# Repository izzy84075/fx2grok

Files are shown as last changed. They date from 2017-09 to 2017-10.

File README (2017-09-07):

-------------------------------------------------------------------------------
README
-------------------------------------------------------------------------------

The sigrok project aims at creating a portable, cross-platform,
Free/Libre/Open-Source signal analysis software suite that supports various
device types (such as logic analyzers, oscilloscopes, multimeters, and more).

The fx2grok device is intended to be the tinyiest possible Open Hardware FX2
eval board (that can be used as 8-channel logic analyzer).

Using the open-source fx2lafw firmware (and sigrok, of course) you can use
this device as 8-channel logic analyzer.

Status
------

fx2grok is currently work in progress. The PCB layout is not yet finished
and no prototypes have yet been made.

Schematics, PCB layout
----------------------

The schematics and PCB layout are available from the fx2grok git repo:

  $ git clone git://sigrok.org/fx2grok

Copyright and license
---------------------

The fx2grok schematics and layout are done from scratch in Kicad, and are
released under the CC-BY-SA 3.0 license.

They are Copyright (C) 2012-2017 Uwe Hermann <uwe@hermann-uwe.de>.

Mailing list
------------

 https://lists.sourceforge.net/lists/listinfo/sigrok-devel

IRC
---

You can find the sigrok developers in the #sigrok IRC channel on Freenode.

Website
-------

 http://sigrok.org/wiki/Fx2grok

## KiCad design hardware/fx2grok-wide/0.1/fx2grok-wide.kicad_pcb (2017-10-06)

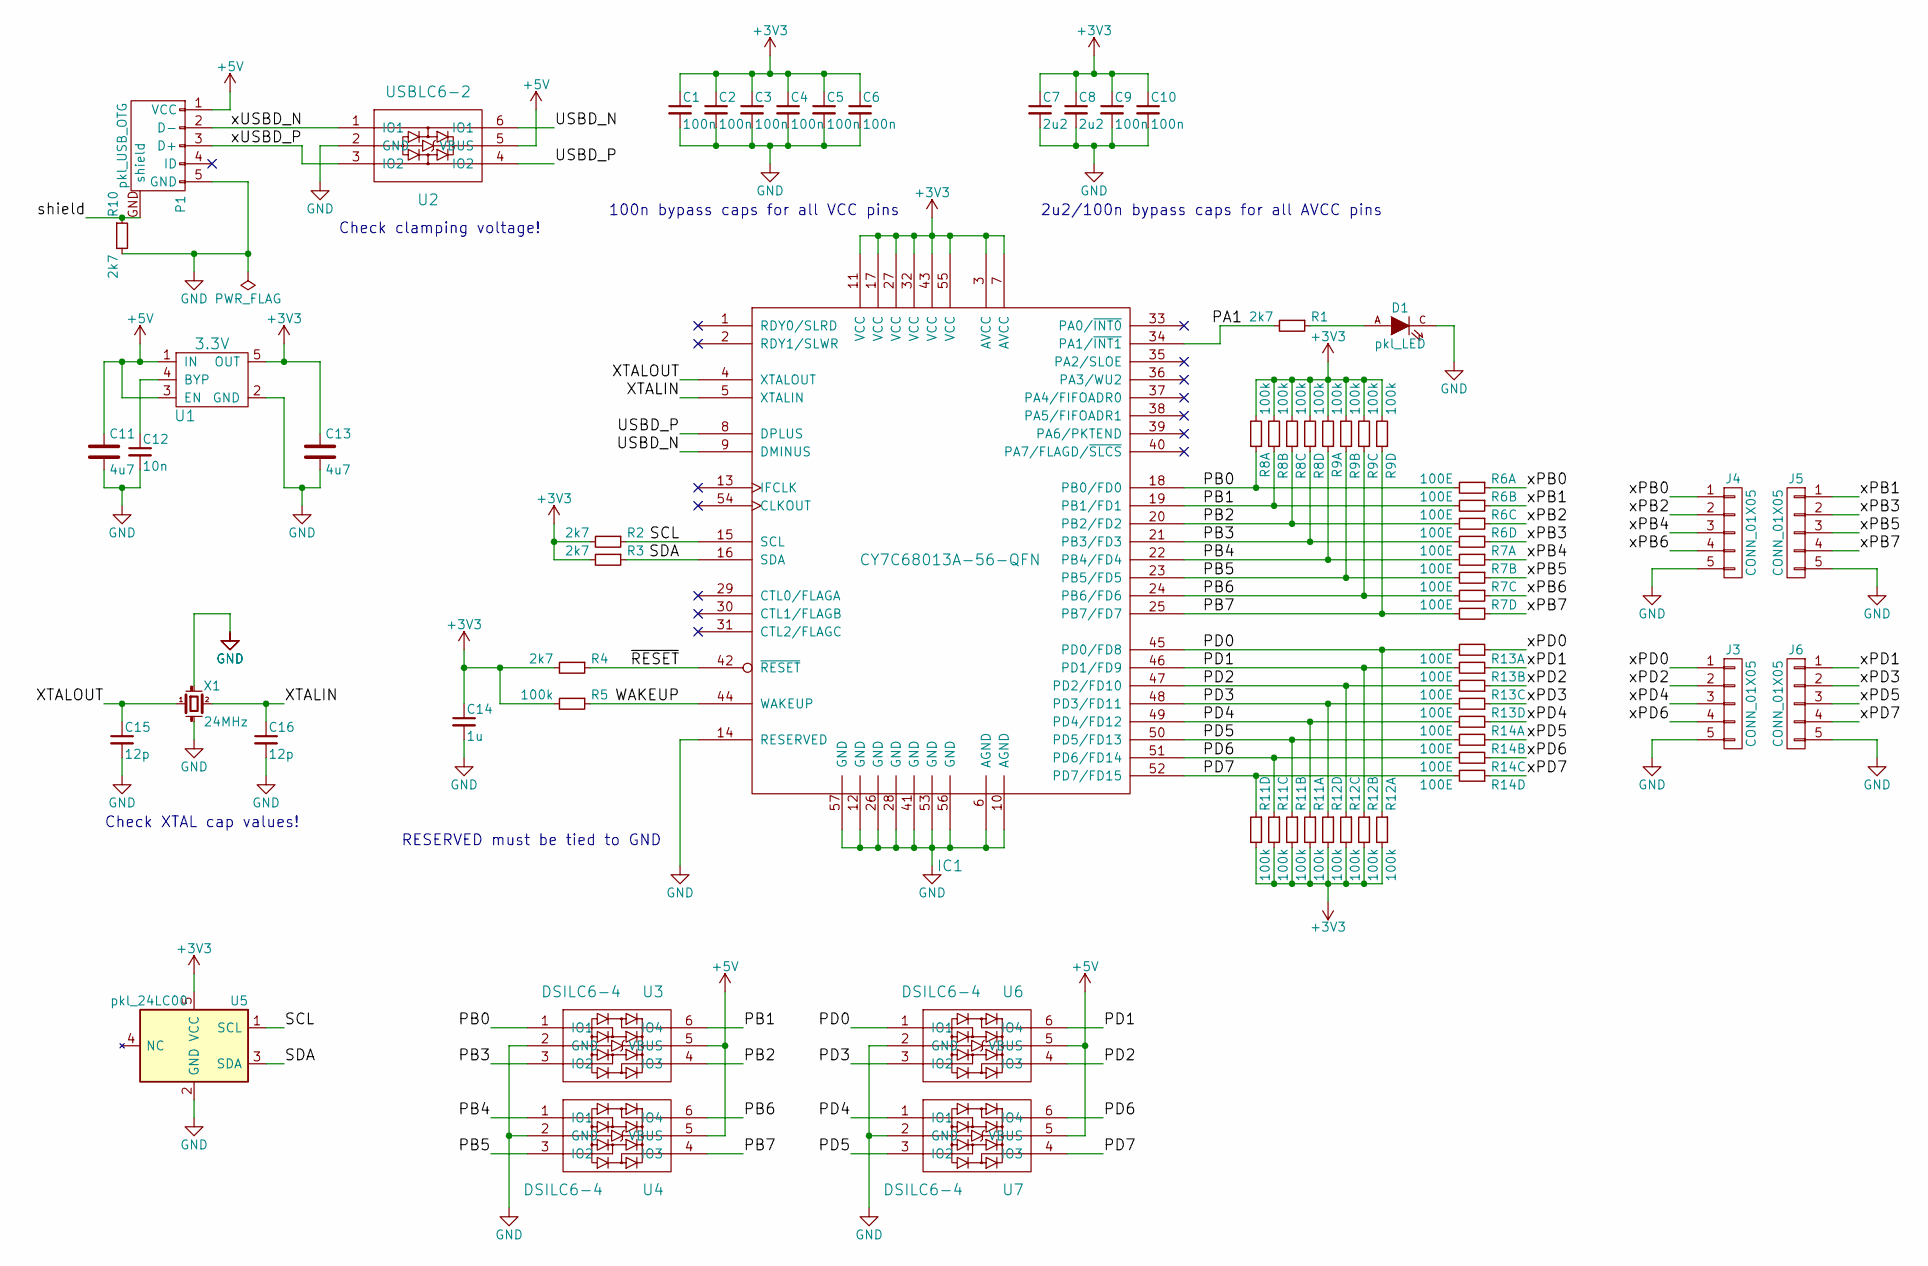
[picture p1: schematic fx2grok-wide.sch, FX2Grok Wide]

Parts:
C1, C2, C3, C4, C5, C6, C9, C10: 100n; C_0402
C7, C8: 2u2; C_0402
C11, C13: 4u7; C_0603
C12: 10n; C_0402
C14: 1u; C_0402
C15, C16: 12p; C_0402
D1: pkl_LED; D_0603
IC1: CY7C68013A-56-QFN; QFN-56-1EP_8x8mm_Pitch0.5mm
J3, J4, J5, J6: CONN_01X05; Pin_Header_Angled_1x05_Pitch1.27mm_SMD
P1: pkl_USB_OTG; Connector_USB_Micro_B_SMD
R1, R2, R3, R4, R10: 2k7; R_0402
R5: 100k; R_0402
R6, R7, R13, R14: 100E; R_Array_Convex_4x0402
R8, R9, R11, R12: 100k; R_Array_Convex_4x0402
U1: 3.3V; SOT-23-5
U2: USBLC6-2; SOT-666
U3, U4, U6, U7: DSILC6-4; SOT-666
U5: pkl_24LC00; SOT-23-5
X1: 24MHz; ABM8

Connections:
+3V3: C1.1, C2.1, C3.1, C4.1, C5.1, C6.1, C7.1, C8.1, C9.1, C10.1, C13.1, C14.1, IC1.3 (AVCC), IC1.7 (AVCC), IC1.11 (VCC), IC1.17 (VCC), IC1.27 (VCC), IC1.32 (VCC), IC1.43 (VCC), IC1.55 (VCC), R2.2, R3.2, R4.2, R5.2, R8.2, R8.4, R8.6, R8.8, R9.2, R9.4, R9.6, R9.8, R11.2, R11.4, R11.6, R11.8, R12.2, R12.4, R12.6, R12.8, U1.5 (OUT), U5.5 (VCC)
+5V: C11.1, P1.1 (VCC), U1.1 (IN), U1.3 (EN), U2.5 (VBUS), U3.5 (VBUS), U4.5 (VBUS), U6.5 (VBUS), U7.5 (VBUS)
/PB0: IC1.18 (PB0/FD0), R6.2, R8.1, U3.1 (IO1)
/PB1: IC1.19 (PB1/FD1), R6.4, R8.3, U3.6 (IO4)
/PB2: IC1.20 (PB2/FD2), R6.6, R8.5, U3.4 (IO3)
/PB3: IC1.21 (PB3/FD3), R6.8, R8.7, U3.3 (IO2)
/PB4: IC1.22 (PB4/FD4), R7.2, R9.1, U4.1 (IO1)
/PB5: IC1.23 (PB5/FD5), R7.4, R9.3, U4.3 (IO2)
/PB6: IC1.24 (PB6/FD6), R7.6, R9.5, U4.6 (IO4)
/PB7: IC1.25 (PB7/FD7), R7.8, R9.7, U4.4 (IO3)
/PD0: IC1.45 (PD0/FD8), R12.1, R13.2, U6.1 (IO1)
/PD1: IC1.46 (PD1/FD9), R12.3, R13.4, U6.6 (IO4)
/PD2: IC1.47 (PD2/FD10), R12.5, R13.6, U6.4 (IO3)
/PD3: IC1.48 (PD3/FD11), R12.7, R13.8, U6.3 (IO2)
/PD4: IC1.49 (PD4/FD12), R11.1, R14.2, U7.1 (IO1)
/PD5: IC1.50 (PD5/FD13), R11.3, R14.4, U7.3 (IO2)
/PD6: IC1.51 (PD6/FD14), R11.5, R14.6, U7.6 (IO4)
/PD7: IC1.52 (PD7/FD15), R11.7, R14.8, U7.4 (IO3)
/SCL: IC1.15 (SCL), R2.1, U5.1 (SCL)
/SDA: IC1.16 (SDA), R3.1, U5.3 (SDA)
/USBD_N: IC1.9 (DMINUS), U2.6 (IO1)
/USBD_P: IC1.8 (DPLUS), U2.4 (IO2)
/WAKEUP: IC1.44 (WAKEUP), R5.1
/XTALIN: C16.1, IC1.5 (XTALIN), X1.2
/XTALOUT: C15.1, IC1.4 (XTALOUT), X1.1
/shield: P1.GND (shield), R10.1
/xPB0: J4.1, R6.1
/xPB1: J5.1, R6.3
/xPB2: J4.2, R6.5
/xPB3: J5.2, R6.7
/xPB4: J4.3, R7.1
/xPB5: J5.3, R7.3
/xPB6: J4.4, R7.5
/xPB7: J5.4, R7.7
/xPD0: J3.1, R13.1
/xPD1: J6.1, R13.3
/xPD2: J3.2, R13.5
/xPD3: J6.2, R13.7
/xPD4: J3.3, R14.1
/xPD5: J6.3, R14.3
/xPD6: J3.4, R14.5
/xPD7: J6.4, R14.7
/xUSBD_N: P1.2 (D-), U2.1 (IO1)
/xUSBD_P: P1.3 (D+), U2.3 (IO2)
/~RESET: IC1.42 (~RESET), R4.1
GND: C1.2, C2.2, C3.2, C4.2, C5.2, C6.2, C7.2, C8.2, C9.2, C10.2, C11.2, C12.2, C13.2, C14.2, C15.2, C16.2, D1.C, IC1.6 (AGND), IC1.10 (AGND), IC1.12 (GND), IC1.14 (RESERVED), IC1.26 (GND), IC1.28 (GND), IC1.41 (GND), IC1.53 (GND), IC1.56 (GND), IC1.57 (GND), J3.5, J4.5, J5.5, J6.5, P1.5 (GND), R10.2, U1.2 (GND), U2.2 (GND), U3.2 (GND), U4.2 (GND), U5.2 (GND), U6.2 (GND), U7.2 (GND), X1.GND (case)
unnamed: C12.1, U1.4 (BYP)
unnamed: D1.A, R1.1
unnamed: IC1.34 (PA1/~INT1), R1.2

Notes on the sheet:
RESERVED must be tied to GND
100n bypass caps for all VCC pins
2u2/100n bypass caps for all AVCC pins
Check XTAL cap values!
Check clamping voltage!

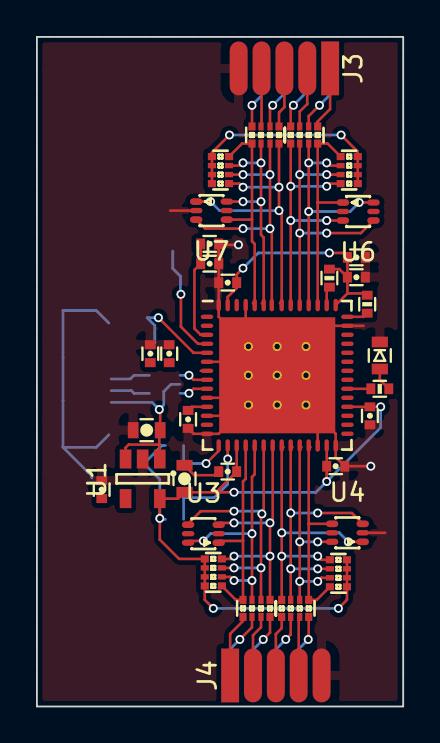
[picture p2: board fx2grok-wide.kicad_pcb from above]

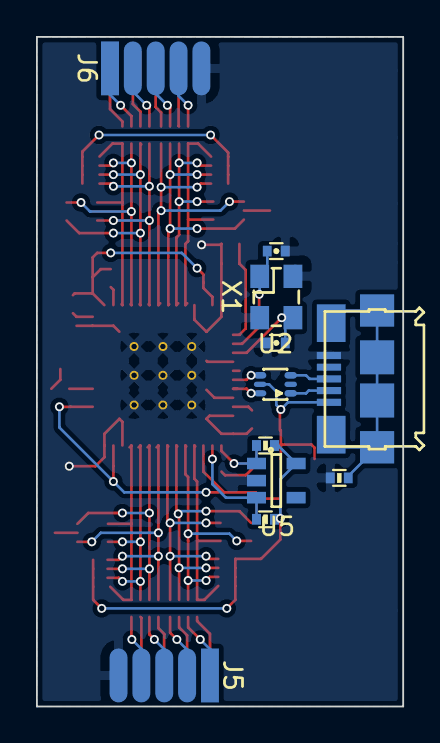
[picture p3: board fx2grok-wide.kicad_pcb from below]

Board: 2 copper layers, 20.3 x 37.2 mm, 45 parts (11 on the bottom side), 49 nets.

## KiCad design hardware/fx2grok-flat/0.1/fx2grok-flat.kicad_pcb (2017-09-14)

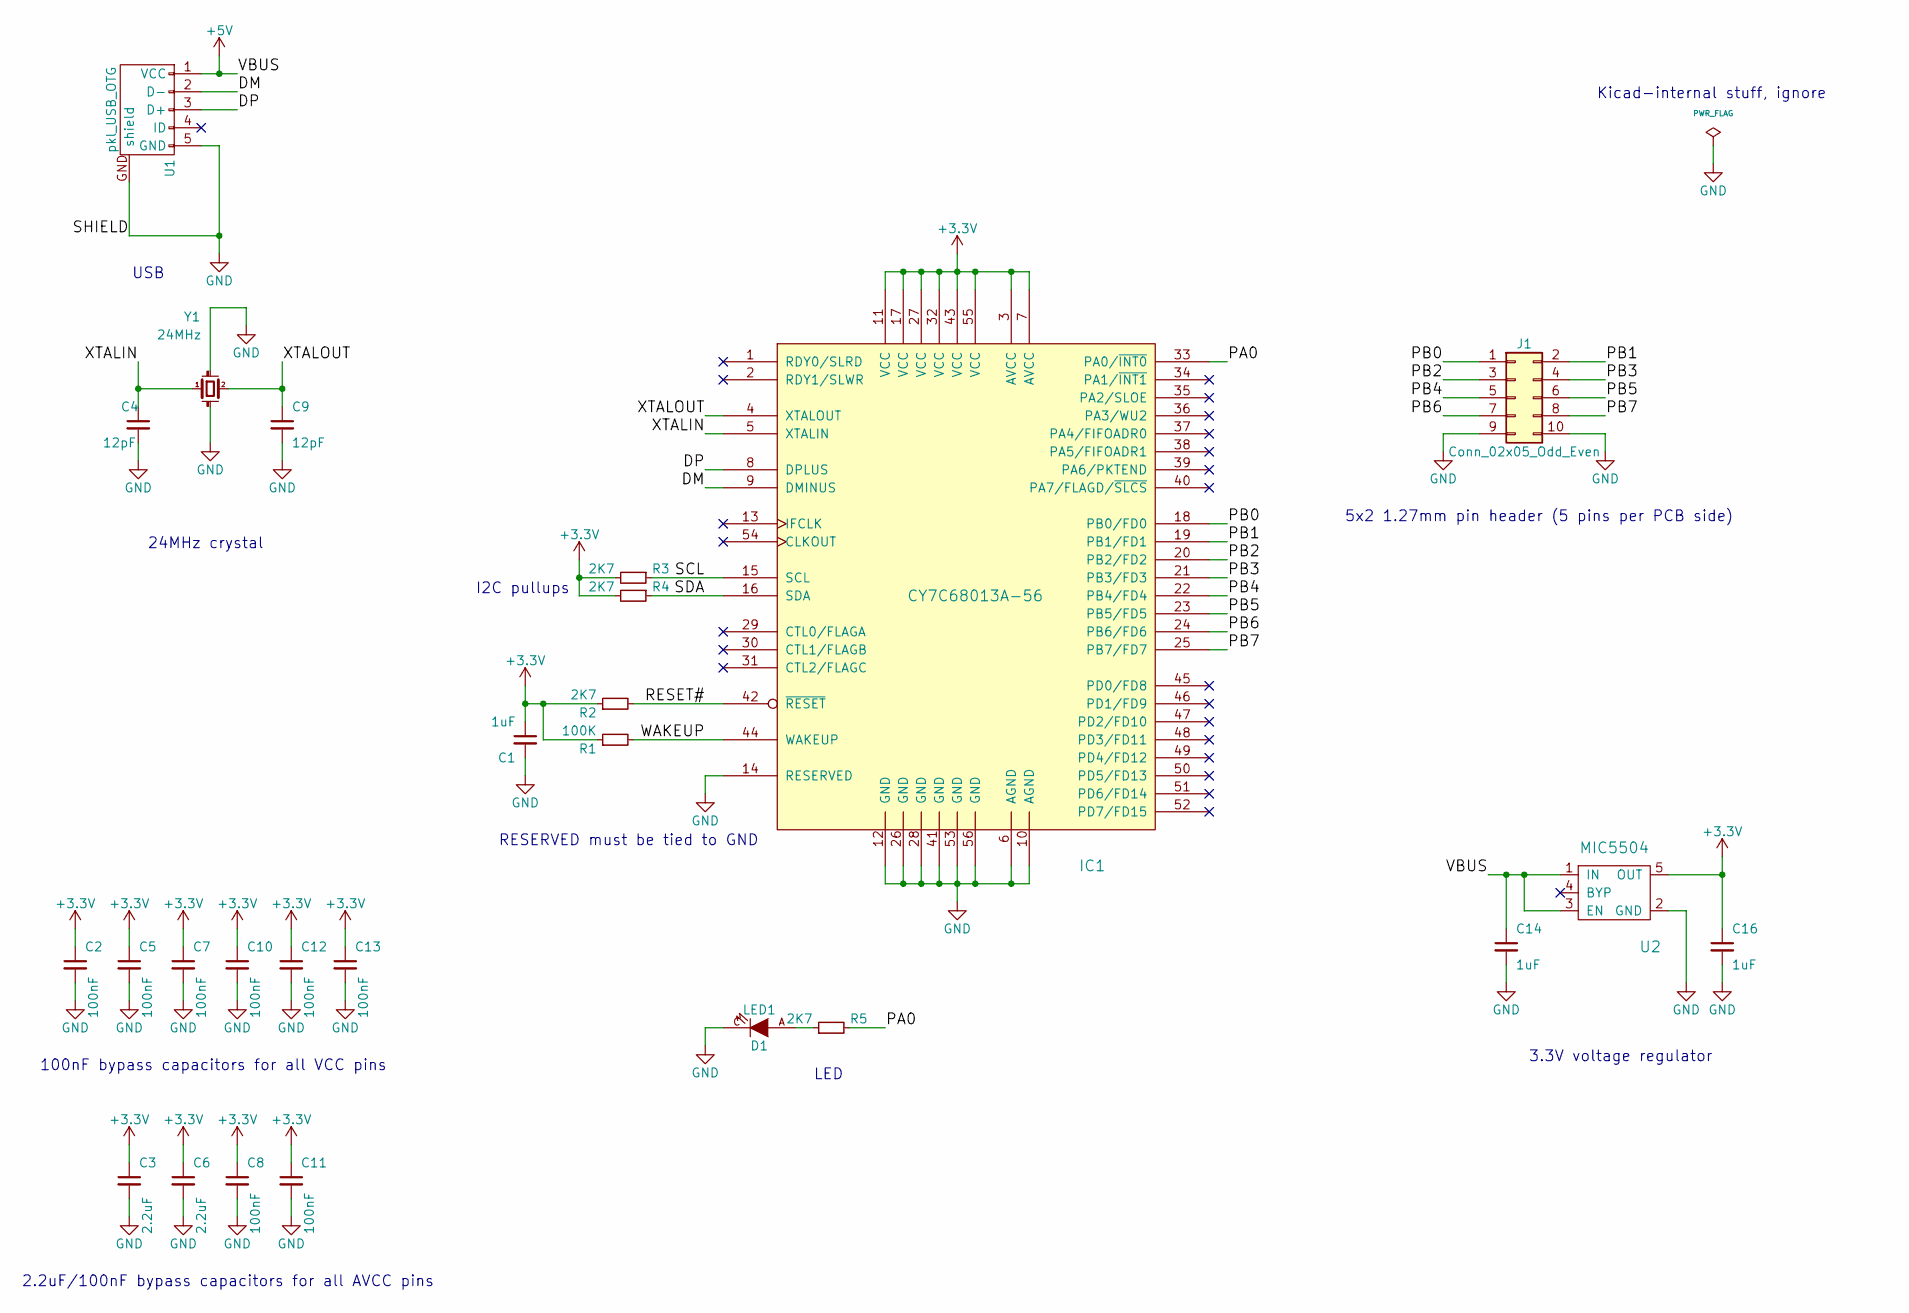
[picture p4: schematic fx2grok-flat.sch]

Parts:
C1, C14, C16: 1uF; C_0402
C2, C5, C7, C8, C10, C11, C12, C13: 100nF; C_0402
C3, C6: 2.2uF; C_0402
C4, C9: 12pF; C_0402
D1: LED1; D_0603
IC1: CY7C68013A-56; QFN-56-1EP_8x8mm_Pitch0.5mm
J1: Conn_02x05_Odd_Even; FTSH-105-XX-X-DV
R1: 100K; R_0402
R2, R3, R4, R5: 2K7; R_0402
U1: pkl_USB_OTG; Connector_USB_Micro_B_SMD
U2: MIC5504; SOT-23-5
Y1: 24MHz; ABM8

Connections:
+3V3: C1.1, C2.1, C3.1, C5.1, C6.1, C7.1, C8.1, C10.1, C11.1, C12.1, C13.1, C16.1, IC1.3 (AVCC), IC1.7 (AVCC), IC1.11 (VCC), IC1.17 (VCC), IC1.27 (VCC), IC1.32 (VCC), IC1.43 (VCC), IC1.55 (VCC), R1.1, R2.1, R3.2, R4.2, U2.5 (OUT)
+5V: C14.1, U1.1 (VCC), U2.1 (IN), U2.3 (EN)
/DM: IC1.9 (DMINUS), U1.2 (D-)
/DP: IC1.8 (DPLUS), U1.3 (D+)
/PA0: IC1.33 (PA0/~INT0), R5.2
/PB0: IC1.18 (PB0/FD0), J1.1
/PB1: IC1.19 (PB1/FD1), J1.2
/PB2: IC1.20 (PB2/FD2), J1.3
/PB3: IC1.21 (PB3/FD3), J1.4
/PB4: IC1.22 (PB4/FD4), J1.5
/PB5: IC1.23 (PB5/FD5), J1.6
/PB6: IC1.24 (PB6/FD6), J1.7
/PB7: IC1.25 (PB7/FD7), J1.8
/RESET#: IC1.42 (~RESET), R2.2
/SCL: IC1.15 (SCL), R3.1
/SDA: IC1.16 (SDA), R4.1
/WAKEUP: IC1.44 (WAKEUP), R1.2
/XTALIN: C4.1, IC1.5 (XTALIN), Y1.1
/XTALOUT: C9.1, IC1.4 (XTALOUT), Y1.2
GND: C1.2, C2.2, C3.2, C4.2, C5.2, C6.2, C7.2, C8.2, C9.2, C10.2, C11.2, C12.2, C13.2, C14.2, C16.2, D1.C, IC1.6 (AGND), IC1.10 (AGND), IC1.12 (GND), IC1.14 (RESERVED), IC1.26 (GND), IC1.28 (GND), IC1.41 (GND), IC1.53 (GND), IC1.56 (GND), J1.9, J1.10, U1.5 (GND), U1.GND (shield), U2.2 (GND), Y1.GND (case)
unnamed: D1.A, R5.1

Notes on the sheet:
5x2 1.27mm pin header (5 pins per PCB side)
Kicad-internal stuff, ignore
LED
24MHz crystal
3.3V voltage regulator
USB
RESERVED must be tied to GND
2.2uF/100nF bypass capacitors for all AVCC pins
100nF bypass capacitors for all VCC pins
I2C pullups

Board: 4 copper layers, 26 parts (0 on the bottom side), 21 nets, no tracks yet.

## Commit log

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2012-06-01 Move files to 0.1 subdir.
    [fx2grok-cube.sch]
2012-06-01 Add fx2grok-cube.lib library to project.
    [fx2grok-cube.sch]
2012-06-01 Place FX2, TLV1117, and USB connector components.
    [fx2grok-cube.sch]
2012-06-01 Fill background of FX2 component.
    [fx2grok-cube.sch]
2012-06-01 Add initial TLV1117 circuitry.
    [fx2grok-cube.sch]
2012-06-01 Add initial USB connector circuitry.
    [fx2grok-cube.sch]
2012-06-01 Add initial XTAL circuitry.
    [fx2grok-cube.sch]
2012-06-01 Add VCC/GND circuitry, mark PA0-7/PD0-7 as no-connect.
    [fx2grok-cube.sch]
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2012-06-02 Add I2C pullups (2.2kOhm).
    Yes, they're needed even though we don't have an I2C EEPROM, see FX2 docs.
    [fx2grok-cube.sch]
2012-06-02 FX2: The RESERVED pin needs to be tied to GND.
    (see FX2 docs)
    [fx2grok-cube.sch]
2012-06-02 FX2: The WAKEUP pin is tied to VCC via a 100K resistor.
    [fx2grok-cube.sch]
2012-06-02 Add 100nF bypass caps for all VCC pins.
    [fx2grok-cube.sch]
2012-06-02 2.2uF/100nF for all AVCC pins (as per docs).
    [fx2grok-cube.sch]
2012-06-02 Use 12pF load capacitors for the crystal.
    [fx2grok-cube.sch]
2012-06-02 Various updates, move stuff around, add pin names.
    [fx2grok-cube.sch]
2012-06-02 RESET# is tied to VCC via a resistor.
    [fx2grok-cube.sch]
2012-06-02 FX2: Use "IC", not "U" for the chip refdes.
    [fx2grok-cube.sch]
2012-06-02 Change Mini-USB B to Micro-USB B connector.
    [fx2grok-cube.sch]
2012-06-03 Replace TLV1117 with MIC5319.
    [fx2grok-cube.sch]
2012-06-03 Add a power LED.
    [fx2grok-cube.sch]
2012-06-03 Add two optional general-purpose LEDs (PD0/1).
    [fx2grok-cube.sch]
2012-06-03 Add resistorpack (8 x 100 Ohm) to PB0-PB7.
    [fx2grok-cube.sch]
2012-06-03 Add footprints for all 0603 parts.
    [fx2grok-cube.sch]
2012-06-03 Bugfix: USB shield pins were not properly connected.
    [fx2grok-cube.sch]
2012-06-03 Fix a few pin types.
2012-06-03 Mark a few more pins as no-connect for now.
    [fx2grok-cube.sch]
2012-06-03 Add some more footprints for symbols.
    [fx2grok-cube.sch]
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2012-06-03 schematic: Add PWR_FLAG (Kicad-internal stuff).
    [fx2grok-cube.sch]
2012-06-03 schematic: Various fixes, add metadata.
    [fx2grok-cube.sch]
2012-06-03 Add missing footprint for the resistorpack.
    [fx2grok-cube.sch]
2012-06-03 schematic: Annotate all components.
    (i.e. turn C? and R? etc. into C12, R27 and so on)
    [fx2grok-cube.sch]
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2012-06-03 schematic: RESET# needs a 2K7 and 1uF (TRM, p. 83).
    Thanks Joel Holdsworth <joel@airwebreathe.org.uk> for pointing this out.
    [fx2grok-cube.sch]
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2012-06-03 Micro-USB B SMD footprint: Add missing SHIELD pin numbers.
2012-06-03 Bugfix: Replace 2-pin CRYSTAL with 4-pin QUARTZCMS4.
    [fx2grok-cube.sch]
2012-06-03 PCB: Set DRC values (min. widths etc).
    [fx2grok-cube.brd]
2012-06-03 PCB: Read in netlist.
    [fx2grok-cube.brd]
2012-06-03 PCB: Disperse parts a bit.
    [fx2grok-cube.brd]
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2012-06-04 schematics: Change all 0603 parts to 0402.
    [fx2grok-cube.sch]
2012-06-04 Update PCB due to netlist changes.
    [fx2grok-cube.brd]
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2012-06-04 schematics: Replace 0603 resistorpack with 0402 one.
    [fx2grok-cube.sch]
2012-06-04 schematics: Add 10pin connector for the probes.
    [fx2grok-cube.sch]
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2012-06-04 Re-read netlist in the PCB.
    [fx2grok-cube.brd]
2012-06-04 PCB: Tigthen DRC settings.
    Use 6mil trace width and trace spacing, 0.3mm min. via diameter,
    0.5 min. hole diameter.
    [fx2grok-cube.brd]
2012-06-05 Draw 16mm x 12mm PCB borders (for now).
    [fx2grok-cube.brd]
2012-06-05 schematics: Fix typo.
    [fx2grok-cube.sch]
2012-06-05 Stuff everything into 12mm x 12mm PCB borders.
    [fx2grok-cube.brd]
2012-06-06 Start arranging components (unfinished).
    [fx2grok-cube.brd]
2012-10-23 schematic: Various simplifications and fixes, regen netlist.
    Drop two LEDs to save space. Use only one pullup for both SCL and SDA
    (should work as I2C is not used anyway). Probe connector: pins 9 + 10 are GND.
    Remove unneeded resistor/bridge for the USB connector SHIELD/GND connection.
    [fx2grok-cube.sch]
2012-10-23 Update PCB to new netlist.
    [fx2grok-cube.brd]
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2012-10-23 Schematics: Fix wiki page URL.
    [fx2grok-cube.sch]
2013-03-25 Schematics: Drop resistor-pack for now.
    The first version (probably all versions) will not have this, since it's
    optional and not strictly required to get an operational device.
    [fx2grok-cube.sch]
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2013-03-26 Replace 5x2 SMD connector with two 5x1 pins/pads.
    We'll use a 5x2 pin header (1.27mm pitch) for now, soldering one 5x1
    half on the top side of the PCB, the other 5x1 on the bottom side of
    the PCB.
    [fx2grok-cube.brd, fx2grok-cube.sch]
2013-04-04 Various updates.
    - Bring back one extra pullup resistor for SCL/SDA.
    - Small fixes and various rearrangements of the PCB components.
    [fx2grok-cube.brd, fx2grok-cube.sch]
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2017-07-09 schematics: Load and resave via Kicad 4.0.5, fixup broken items.
    Fix broken wires, fix missing or broken symbols, update some symbols to
    the current Kicad versions, re-run "annotate schematic".
    [fx2grok-cube.sch]
2017-07-09 layout: Load and resave via Kicad 4.0.5, update from netlist.
    [fx2grok-cube.brd, fx2grok-cube.kicad_pcb]
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2017-07-09 Replace crystal symbol with a 4-pin SMD crystal variant.
    [fx2grok-tiny.kicad_pcb, fx2grok-tiny.sch]
2017-09-07 Finish initial layout, fixup various details.
    [fx2grok-tiny.kicad_pcb]
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2017-09-07 Set solder mask clearance to 2mil / 0.05mm.
    [fx2grok-tiny.kicad_pcb]
2017-09-07 Set board thickness to 0.8mm.
    This is required so that the 2x5 1.27mm pin headers will fit.
    [fx2grok-tiny.kicad_pcb]
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2017-09-07 List the board dimensions on the drawings layer.
    [fx2grok-tiny.kicad_pcb]
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2017-09-07 Rename old layer names to new F.Cu and B.Cu.
    [fx2grok-tiny.kicad_pcb]
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2017-09-07 Move/resize "fx2grok" text to avoid overlap with silkscreen.
    [fx2grok-tiny.kicad_pcb]
2017-09-07 Set grid origin to lower-left corner of the PCB.
    [fx2grok-tiny.kicad_pcb]
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2017-09-08 Add 0/1/GND pin markings on the 5x2 1.27mm connector.
    [fx2grok-tiny.kicad_pcb]
2017-09-08 Fix C16 silkscreen placement.
    [fx2grok-tiny.kicad_pcb]
2017-09-08 Avoid P1/P2 silkscreen overlapping the 0/1/G copper markings.
    [fx2grok-tiny.kicad_pcb]
2017-09-08 Added solder stop openings over copper legend text.
    It is necessary to add openings in the solder stop to text on the copper
    layer, otherwise it is not readable.
    [fx2grok-tiny.kicad_pcb]
2017-09-08 schematics: Change LDO to Micrel MIC5504.
    300mA should be enough, and this one is cheaper and we can also drop
    one of the capacitors as well.
    [fx2grok-tiny.sch]
2017-09-08 layout: Update due to MIC5504 change, minor USB connector fixup.
    [fx2grok-tiny.kicad_pcb]
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2017-09-17 Added eeprom and pullups on probe inputs. Started routing.
    [fx2grok-flat.kicad_pcb, fx2grok-flat.sch]
2017-10-03 Add the first version of the schematic for the fx2grok-wide.
    [fx2grok-wide.sch]
2017-10-04 Switch the LED to PA1, and start laying out the PCB.
    [fx2grok-wide.kicad_pcb, fx2grok-wide.sch]
2017-10-06 Switch to a different footprint for the FX2, and make the input connectors SMD pads on both sides of the PCB(Can stick a 2x5 through-hole header over the side of the PCB and solder it on). Made a bun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
    [fx2grok-wide.kicad_pcb, fx2grok-wide.sch]
2017-10-06 Switch back to the old FX2 footprint, add the center pad of the QFN to the schematic symbol, and connect it to ground as recommended by Cypress. And connect a few more traces.
    [fx2grok-wide.kicad_pcb, fx2grok-wide.sch]

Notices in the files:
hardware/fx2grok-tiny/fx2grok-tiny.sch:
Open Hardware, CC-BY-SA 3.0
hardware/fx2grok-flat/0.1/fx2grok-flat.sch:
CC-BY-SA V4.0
